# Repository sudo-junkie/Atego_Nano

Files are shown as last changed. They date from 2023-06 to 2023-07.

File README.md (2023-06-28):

# Atego Nano

KiCad 7 design files (schematic, PCB, gerber, BOM) for an Arduino Nano clone, with the following additional features:
-	Single cell lithium battery charger
-	VIN upto 15V
-	USB C
-	RGB LEDs

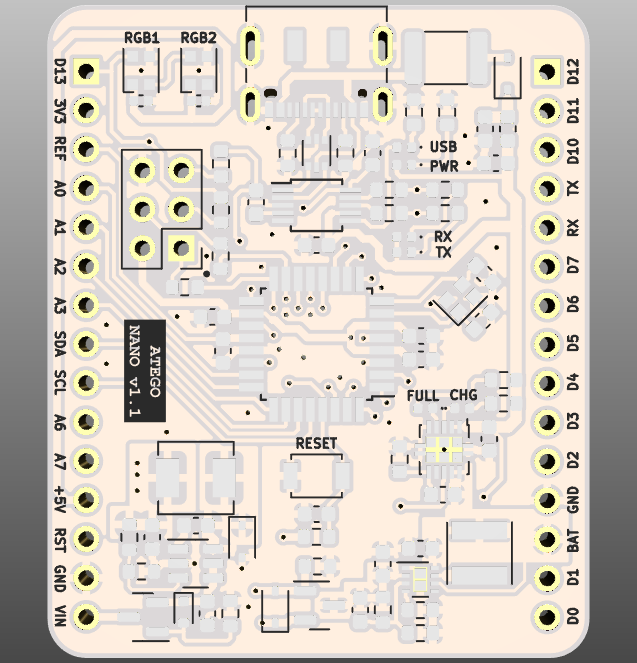
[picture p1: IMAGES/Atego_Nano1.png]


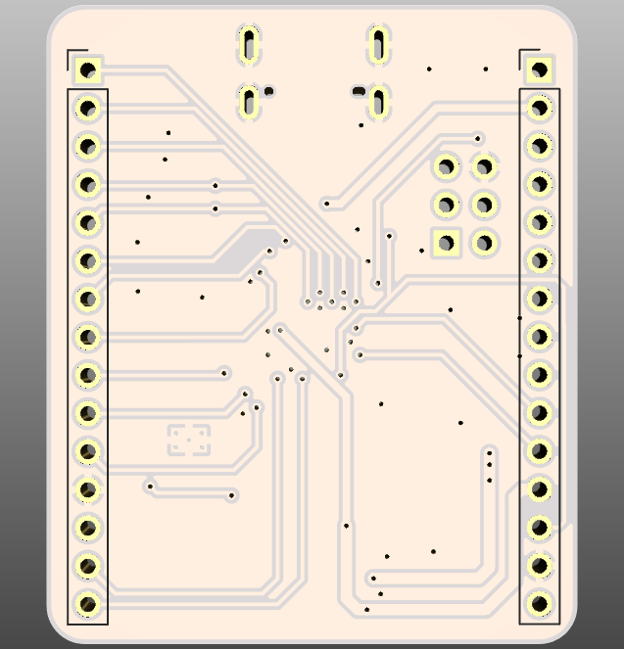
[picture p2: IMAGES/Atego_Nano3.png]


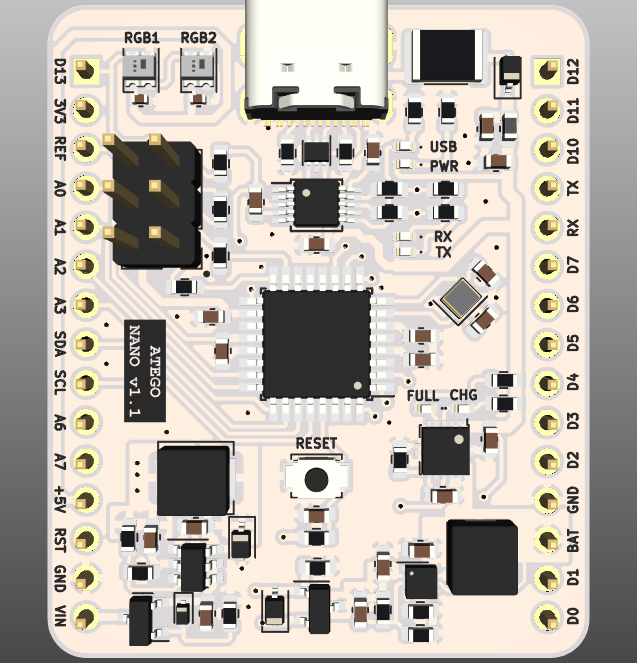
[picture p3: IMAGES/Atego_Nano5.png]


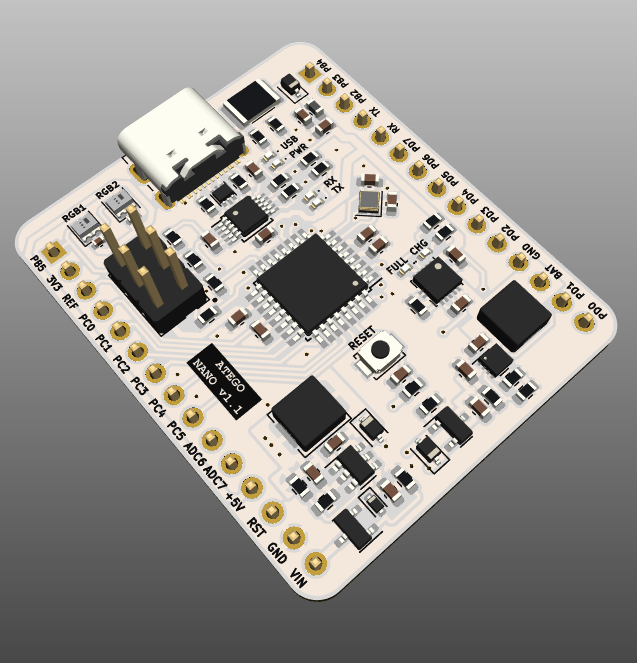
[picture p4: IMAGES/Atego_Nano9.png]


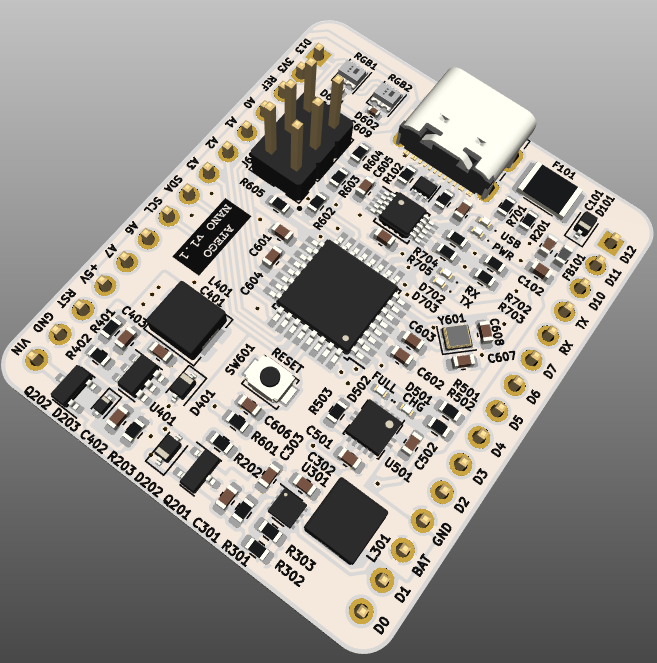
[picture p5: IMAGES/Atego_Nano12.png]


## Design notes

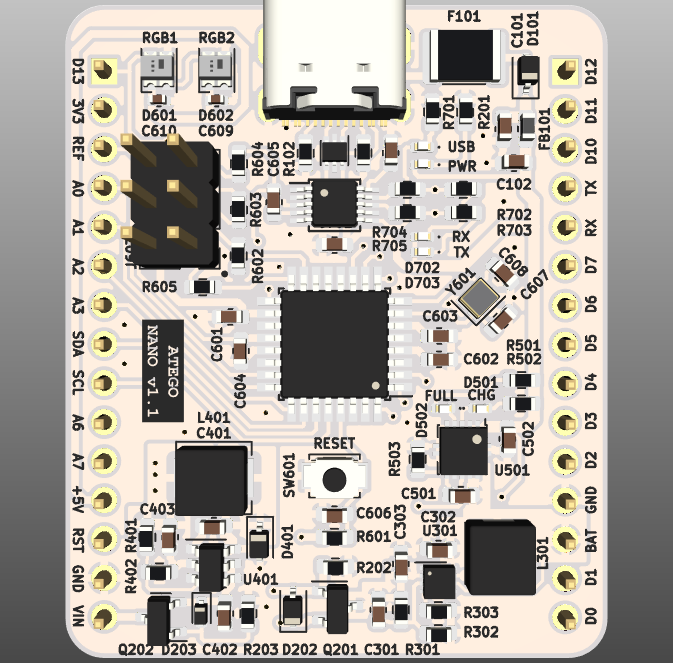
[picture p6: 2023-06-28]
IMAGES/Atego_Nano4.png

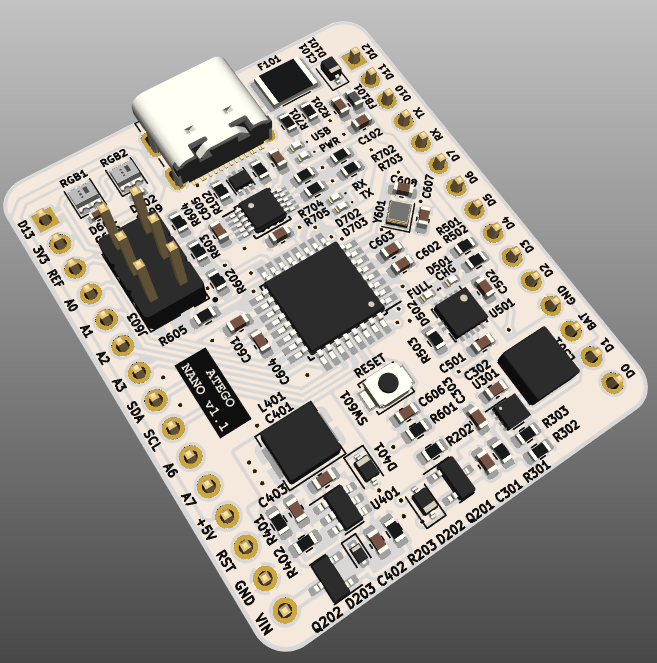
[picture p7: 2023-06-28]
IMAGES/Atego_Nano11.png

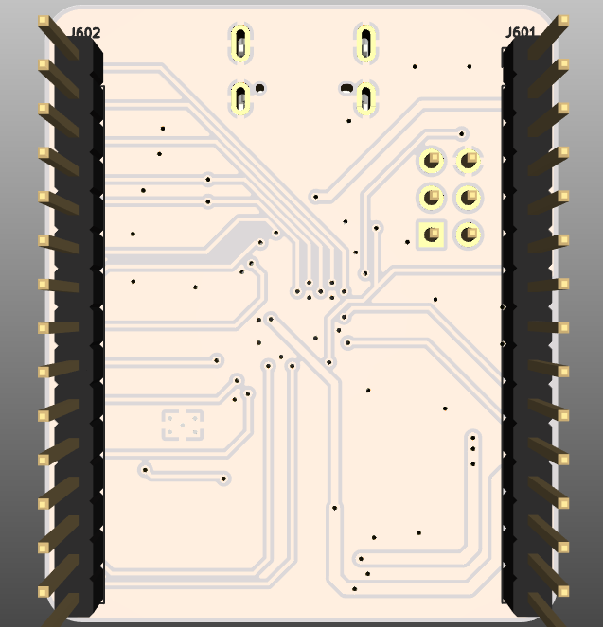
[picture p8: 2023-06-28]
IMAGES/Atego_Nano6.png

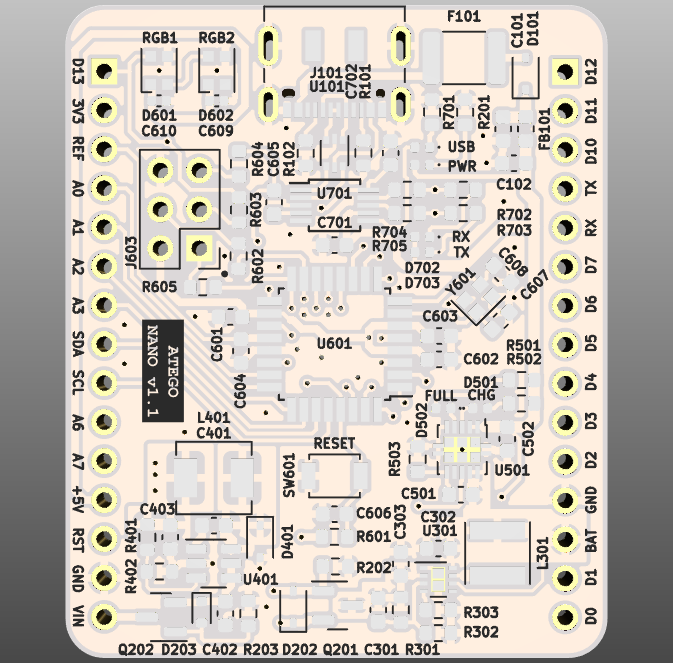
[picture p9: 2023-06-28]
IMAGES/Atego_Nano.png

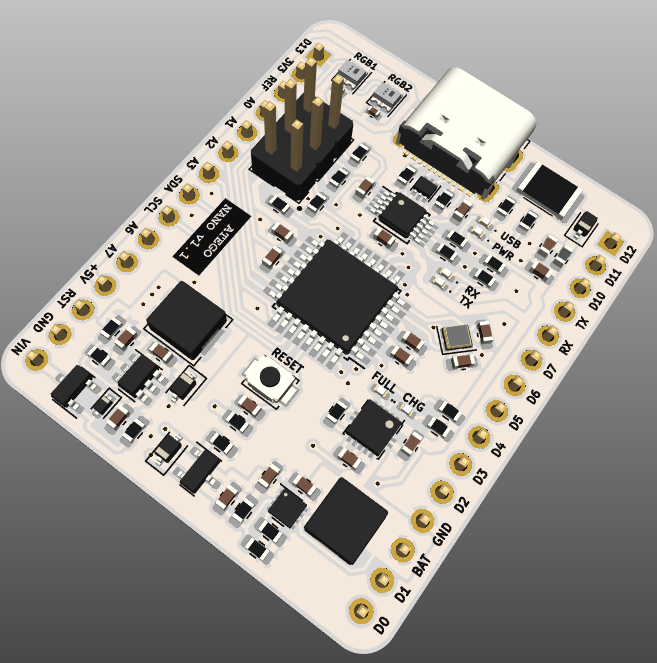
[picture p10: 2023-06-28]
IMAGES/Atego_Nano10.png

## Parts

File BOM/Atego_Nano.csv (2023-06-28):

Reference | Value | Footprint | MPN | MANUFACTURER | Price | Vendor | Qty
C101, C102, C602, C605, C606 | 1u 10% 10V | Capacitor_SMD:C_0603_1608Metric | CC0603KRX7R6BB105 | YAGEO | 0.0032 | LCSC | 5
C301 | 100p 1% 50V | Capacitor_SMD:C_0603_1608Metric | CC0603FRNPO9BN101 | YAGEO | 0.0086 | LCSC | 1
C302, C402 | 10u 20% 25V | Capacitor_SMD:C_0603_1608Metric | CC0603MRX5R8BB106 | YAGEO | 0.0427 | LCSC | 2
C303, C403 | 22u 20% 10V | Capacitor_SMD:C_0603_1608Metric | CC0603MRX5R6BB226 | YAGEO | 0.0352 | LCSC | 2
C401 | 10n 10% 10V | Capacitor_SMD:C_0603_1608Metric | CC0603KRX7R6BB103 | YAGEO | 0.004 | LCSC | 1
C501, C601, C603, C604, C701, C702 | 100n 10% 10V | Capacitor_SMD:C_0603_1608Metric | CC0603KRX7R6BB104 | YAGEO | 0.0032 | LCSC | 6
C502 | 470n 10% 16V | Capacitor_SMD:C_0603_1608Metric | CC0603KRX7R7BB474 | YAGEO | 0.0075 | LCSC | 1
C607, C608 | 22p 1% 50V | Capacitor_SMD:C_0603_1608Metric | CC0603FRNPO9BN220 | YAGEO | 0.0089 | LCSC | 2
C609, C610 | 100n 10V 5% | Capacitor_SMD:C_0402_1005Metric | CC0402JRX7R6BB104 | YAGEO | 0.0017 | LCSC | 2
D101, D202, D401 | ES3A-ES3J | Diode_SMD:D_SOD-323 | ES3AF | Shandong Jingdao Microelectronics | 0.0374 | LCSC | 3
D201 | LED_PWR | LED_SMD:LED_0402_1005Metric | XL-1005SURC | XINGLIGHT | 0.0067 | LCSC | 1
D203 | 11V | Diode_SMD:D_SOD-523 | BZX584C11V | Yangzhou Yangjie Elec Tech | 0.0147 | LCSC | 1
D501 | LED_R | LED_SMD:LED_0402_1005Metric | XL-1005SURC | XINGLIGHT | 0.0067 | LCSC | 1
D502 | LED_G | LED_SMD:LED_0402_1005Metric | XL-1005UGC | XINGLIGHT | 0.0067 | LCSC | 1
D601, D602 | WS2812B | LED_SMD:LED_WS2812B-2020_PLCC4_2.0x2.0mm | XL-2020RGBC-WS2812B | XINGLIGHT | 0.0738 | LCSC | 2
D701 | LED_USB_ACT | LED_SMD:LED_0402_1005Metric | XL-1005UBC | XINGLIGHT | 0.0066 | LCSC | 1
D702 | LED_TX | LED_SMD:LED_0402_1005Metric | XL-1005UOC | XINGLIGHT | 0.01 | LCSC | 1
D703 | LED_RX | LED_SMD:LED_0402_1005Metric | XL-1005UOC | XINGLIGHT | 0.01 | LCSC | 1
F101 | 500mA | Resistor_SMD:R_1812_4532Metric | MF-MSMF050-2 | BOURNS | 0.046 | LCSC | 1
FB101 | 220R@100MHz 1.5A | Inductor_SMD:L_0603_1608Metric | HPZ1608D221-1R5TF | Sunlord | 0.0146 | LCSC | 1
J101 | USB_C_Receptacle_USB2.0 | Connector_USB:USB_C_Receptacle_JAE_DX07S016JA1R1500 | TYPE-C 24P QT 143 | SHOU HAN | 0.3264 | LCSC | 1
J601 | Conn_L | Connector_PinHeader_2.54mm:PinHeader_1x15_P2.54mm_Vertical | B-2100S15P-A110 | Ckmtw(Shenzhen Cankemeng) | 0.0732 | LCSC | 1
J602 | Conn_R | Connector_PinHeader_2.54mm:PinHeader_1x15_P2.54mm_Vertical | B-2100S15P-A110 | Ckmtw(Shenzhen Cankemeng) | 0.0732 | LCSC | 1
J603 | Conn_ICSP | Connector_PinHeader_2.54mm:PinHeader_2x03_P2.54mm_Vertical | PH-01291 | Liansheng | 0.0207 | LCSC | 1
L301 | 1u | Inductor_SMD:L_Vishay_IFSC-1515AH_4x4x1.8mm | PSPNAQ4018-1R0M | PROD Tech | 0.0398 | LCSC | 1
L401 | 4u7 | Inductor_SMD:L_Sunlord_MWSA0402S | PSPMAA0402-4R7M-ANP | PROD Tech | 0.1549 | LCSC | 1
Q201, Q202 | AO3401A | Package_TO_SOT_SMD:SOT-23 | AO3401CI-MS | MSKSEMI | 0.0275 | LCSC | 2
R101, R102 | 5K1 5% | Resistor_SMD:R_0603_1608Metric | RC0603JR-075K1L | YAGEO | 0.0011 | LCSC | 2
R201, R501-R503, R602-R605, R701, R704, R705 | 1K 0.1% | Resistor_SMD:R_0603_1608Metric | RT0603BRD071KL | YAGEO | 0.0227 | LCSC | 11
R202, R203, R303, R601 | 10K 0.1% | Resistor_SMD:R_0603_1608Metric | RT0603BRD0710KL | YAGEO | 0.0222 | LCSC | 4
R301 | 768K | Resistor_SMD:R_0603_1608Metric | PTFR0603B768KP9 | Resistor.Today | 0.1092 | LCSC | 1
R302 | 243K | Resistor_SMD:R_0603_1608Metric | RT0603BRD07243KL | YAGEO | 0.028 | LCSC | 1
R401 | 180K 0.1% | Resistor_SMD:R_0603_1608Metric | RT0603BRD07180KL | YAGEO | 0.0238 | LCSC | 1
R402 | 33K | Resistor_SMD:R_0603_1608Metric | RT0603BRD0733KL | YAGEO | 0.0266 | LCSC | 1
R702, R703 | 470R 5% | Resistor_SMD:R_0603_1608Metric | RC0603JR-07470RL | YAGEO | 0.001 | LCSC | 2
SW601 | SW_RST | Button_Switch_SMD:SW_SPST_B3U-1000P | B3U-1000P | Omron Electronics | 0.2648 | LCSC | 1
U101 | USBLC6-2P6 | Package_TO_SOT_SMD:SOT-666 | USBLC6-2P6-ES | ElecSuper | 0.0816 | LCSC | 1
U301 | TPS61252DSG | Package_SON:WSON-8-1EP_2x2mm_P0.5mm_EP0.9x1.6mm | TPS61252DSGR | Texas Instruments | 1.7691 | LCSC | 1
U401 | AP3211K | Package_TO_SOT_SMD:SOT-23-6 | AP3211KTR-G1 | Diodes Incorporated | 0.1901 | LCSC | 1
U501 | BQ24012 | Package_SON:VSON-10-1EP_3x3mm_P0.5mm_EP1.65x2.4mm_ThermalVias | BQ24012DRCR | Texas Instruments | 1.8169 | LCSC | 1
U601 | ATmega328P-A | Package_QFP:TQFP-32_7x7mm_P0.8mm | ATMEGA328P-AU | Microchip Tech | 2.4246 | LCSC | 1
U701 | CH340E | Package_SO:MSOP-10_3x3mm_P0.5mm | CH340E | WCH(Jiangsu Qin Heng) | 0.5807 | LCSC | 1
Y601 | 16MHz | Crystal:Crystal_SMD_2016-4Pin_2.0x1.6mm | TJ2116000UYGBC | JYJE | 0.1504 | LCSC | 1

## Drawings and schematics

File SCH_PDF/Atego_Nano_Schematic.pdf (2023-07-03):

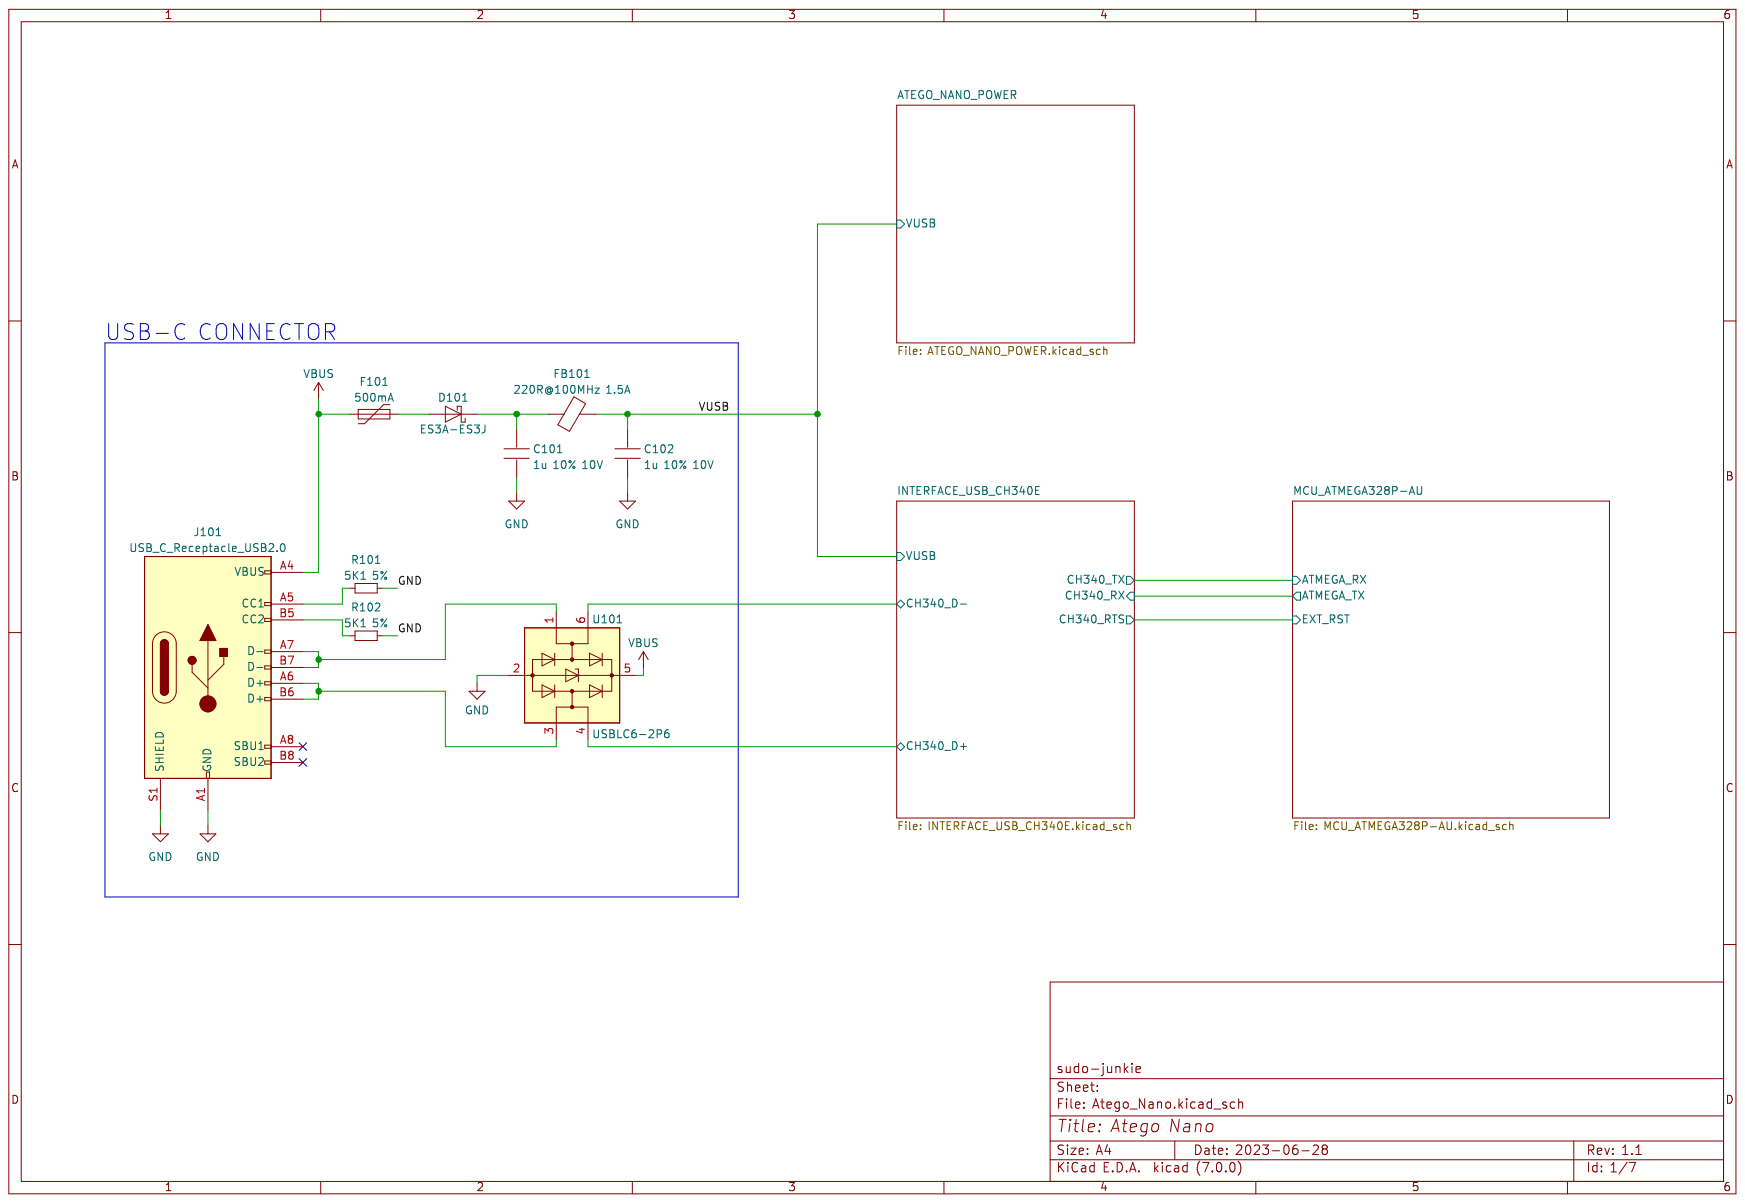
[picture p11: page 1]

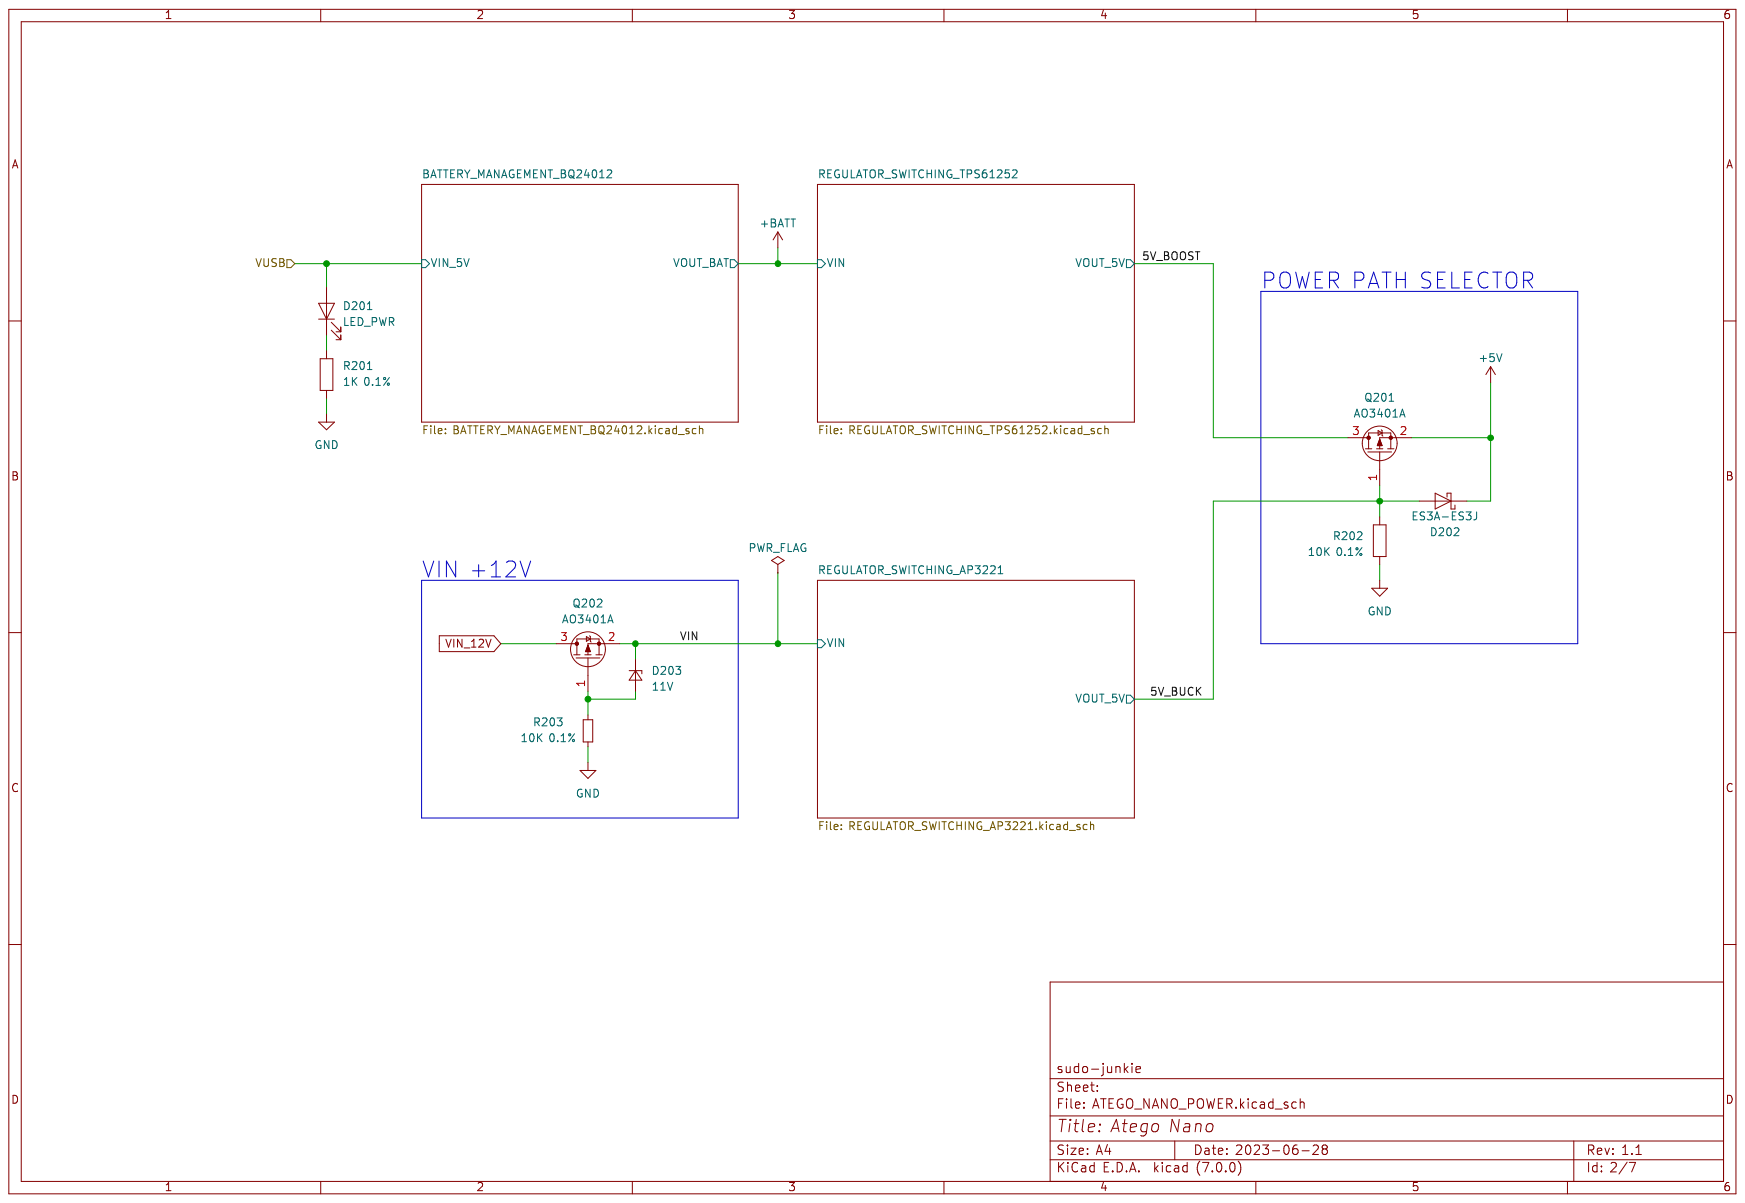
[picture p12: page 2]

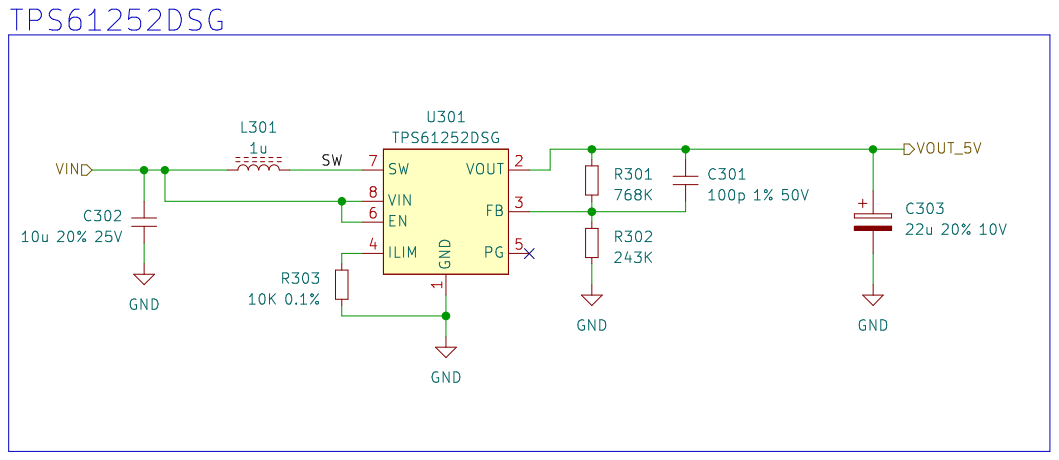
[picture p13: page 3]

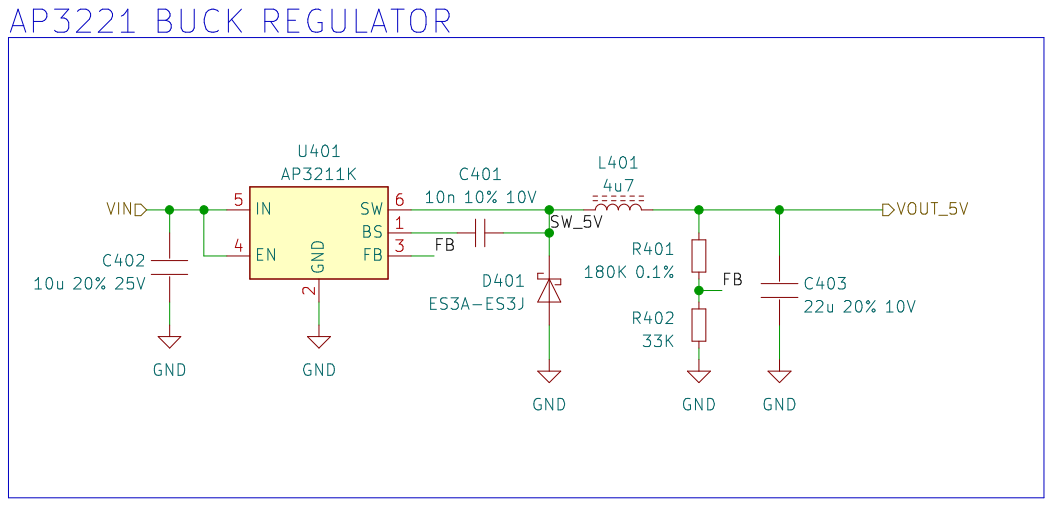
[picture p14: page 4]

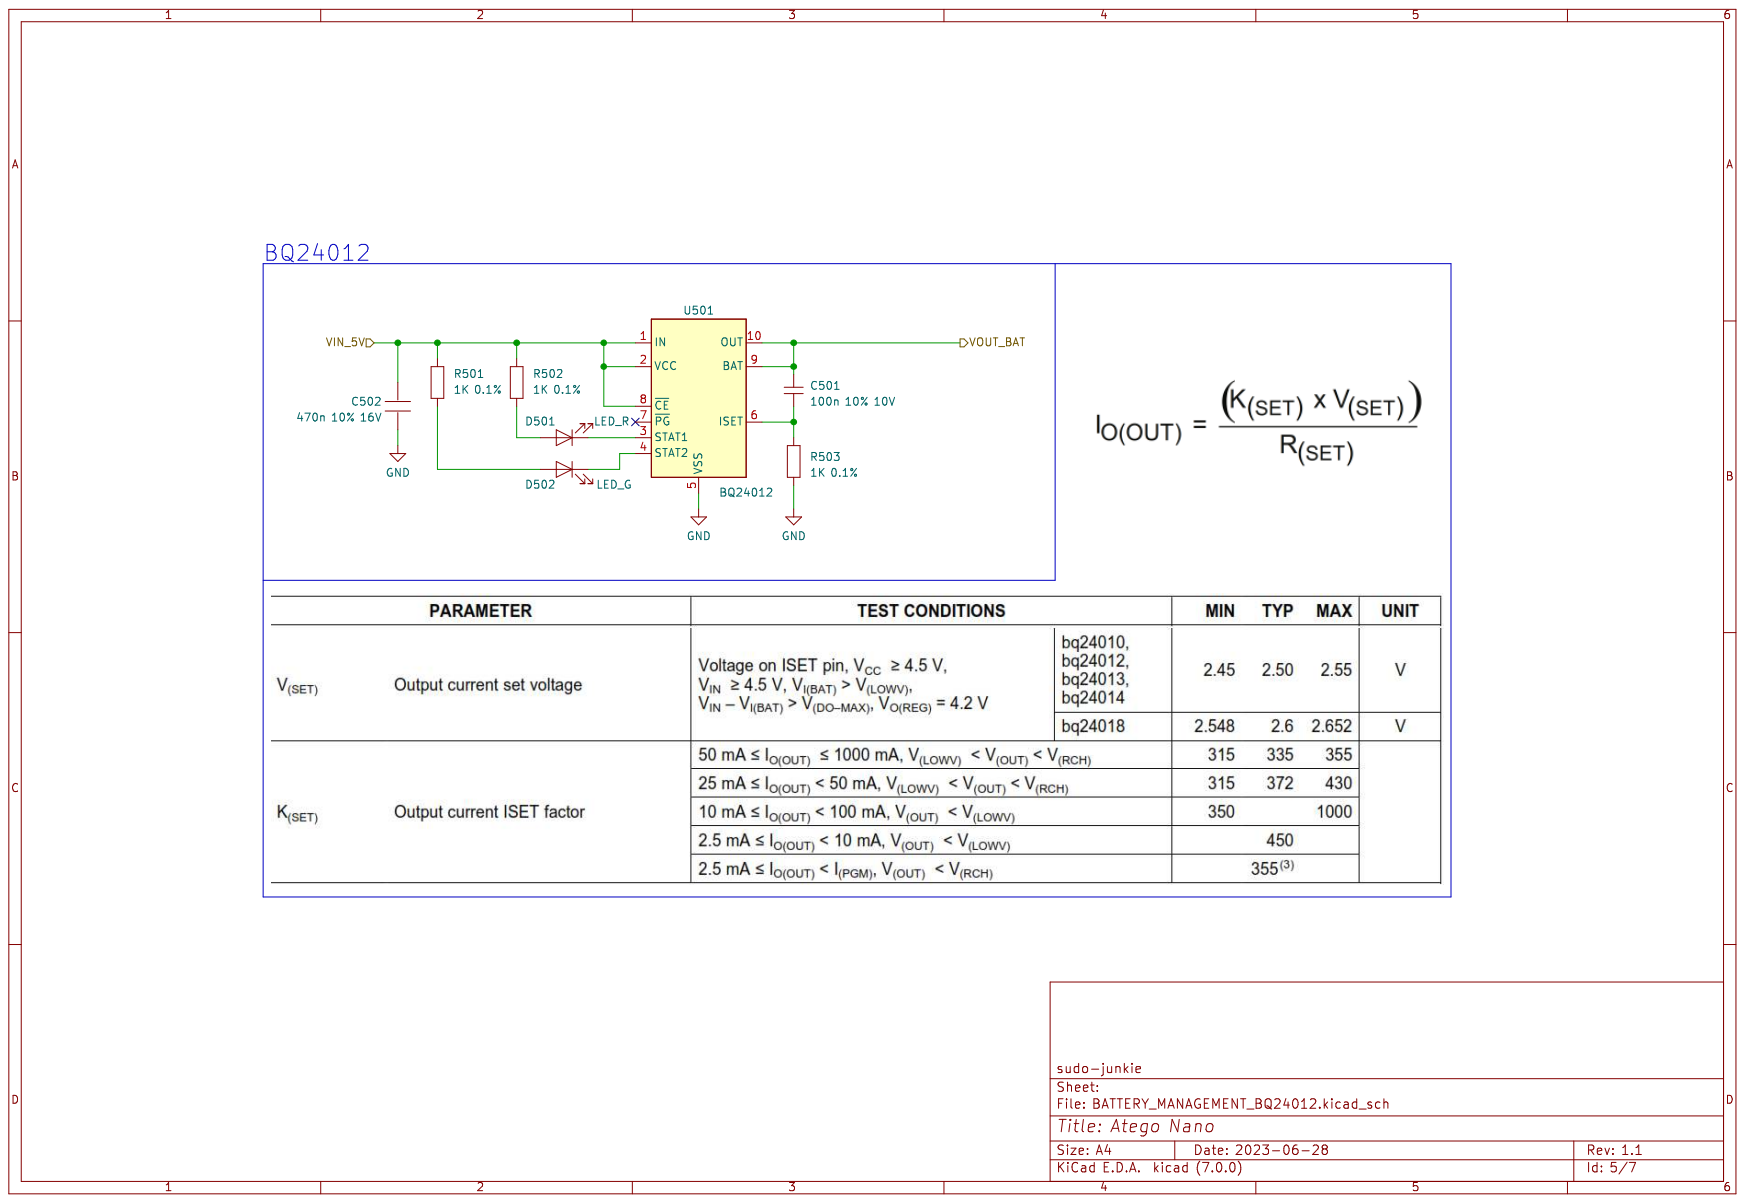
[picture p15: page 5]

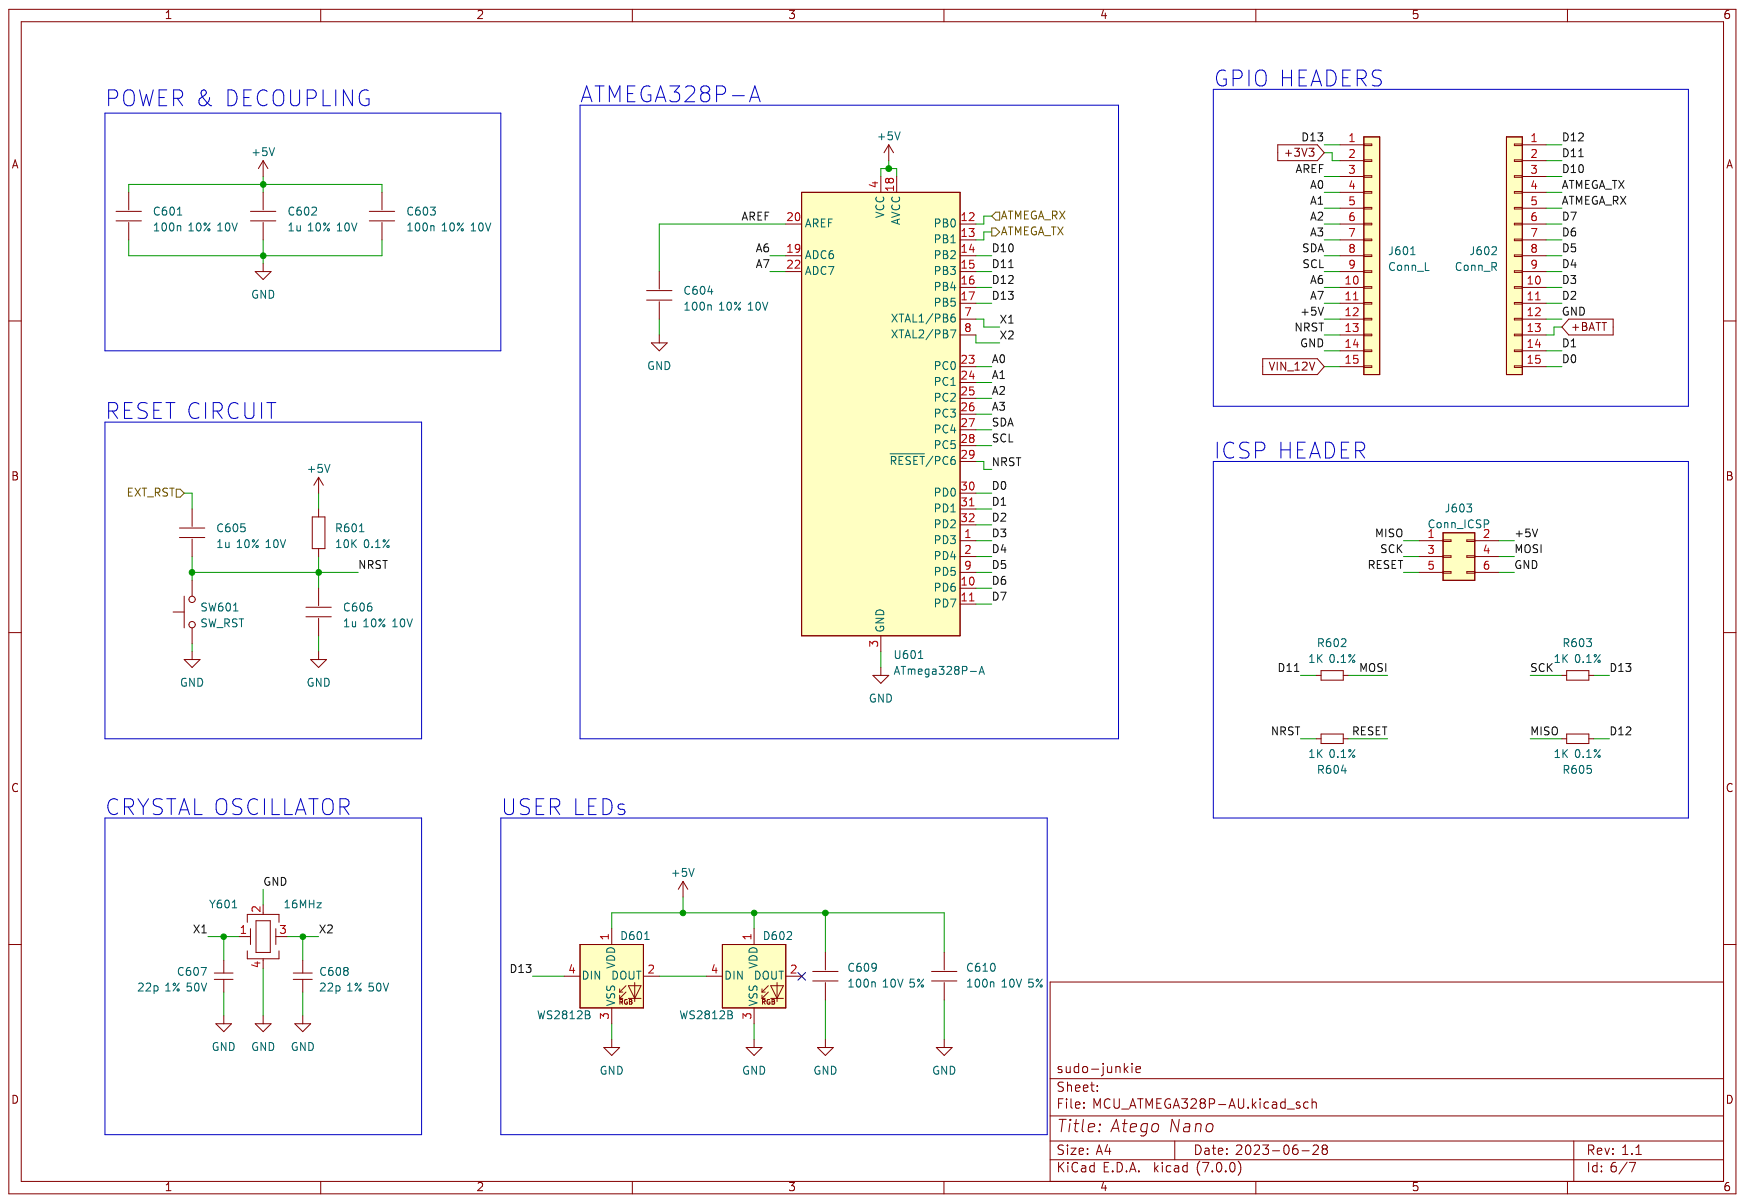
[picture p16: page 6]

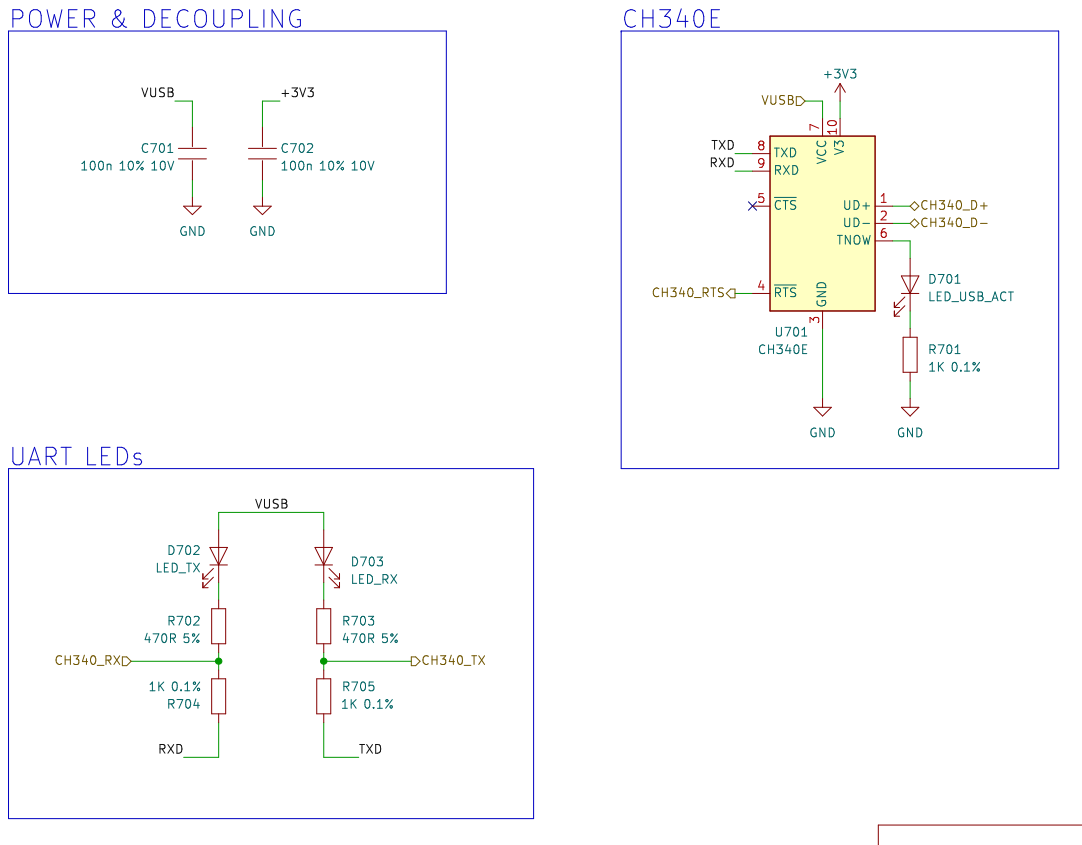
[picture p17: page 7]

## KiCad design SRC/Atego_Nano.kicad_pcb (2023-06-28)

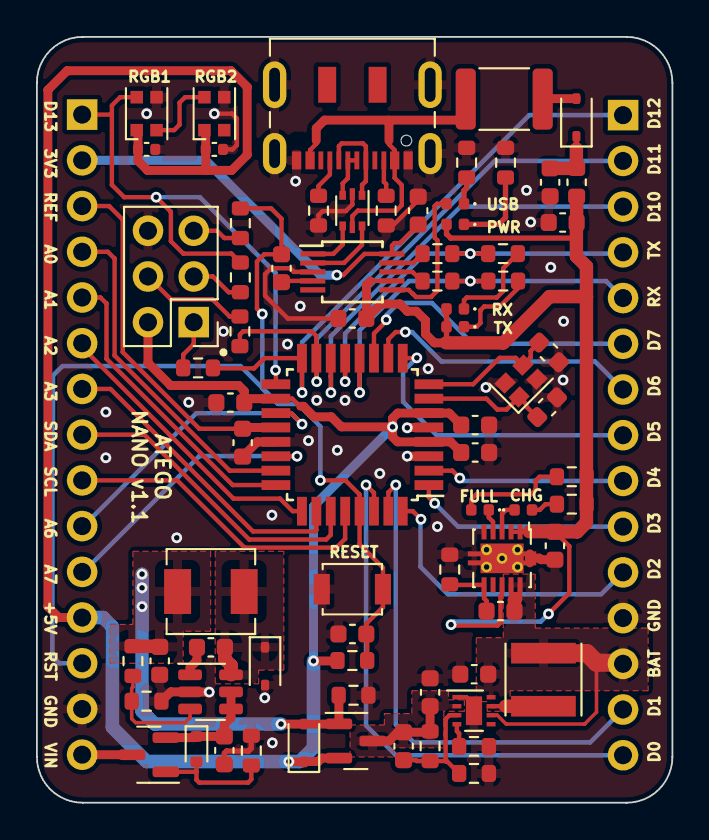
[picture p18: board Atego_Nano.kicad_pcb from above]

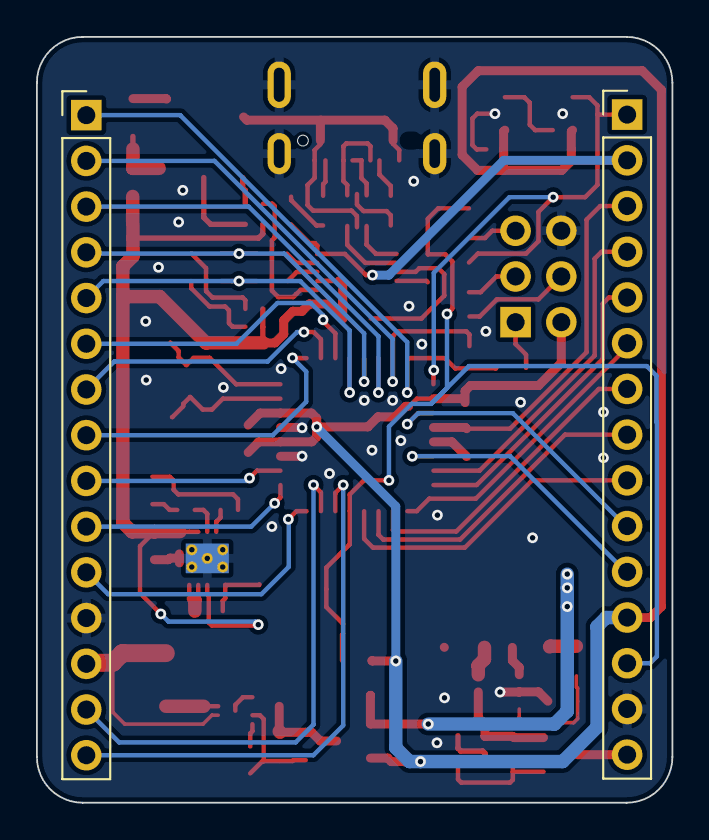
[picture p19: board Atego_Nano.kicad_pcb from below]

Board: 2 copper layers, 35.3 x 42.5 mm, 75 parts (2 on the bottom side), 69 nets.

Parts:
C101, C102, C602, C605, C606: 1u 10% 10V; C_0603_1608Metric
C301: 100p 1% 50V; C_0603_1608Metric
C302, C402: 10u 20% 25V; C_0603_1608Metric
C303, C403: 22u 20% 10V; C_0603_1608Metric
C401: 10n 10% 10V; C_0603_1608Metric
C501, C601, C603, C604, C701, C702: 100n 10% 10V; C_0603_1608Metric
C502: 470n 10% 16V; C_0603_1608Metric
C607, C608: 22p 1% 50V; C_0603_1608Metric
C609, C610: 100n 10V 5%; C_0402_1005Metric
D101, D202, D401: ES3A-ES3J; D_SOD-323
D201: LED_PWR; LED_0402_1005Metric
D203: 11V; D_SOD-523
D501: LED_R; LED_0402_1005Metric
D502: LED_G; LED_0402_1005Metric
D601, D602: WS2812B; LED_WS2812B-2020_PLCC4_2.0x2.0mm
D701: LED_USB_ACT; LED_0402_1005Metric
D702: LED_TX; LED_0402_1005Metric
D703: LED_RX; LED_0402_1005Metric
F101: 500mA; R_1812_4532Metric
FB101: 220R@100MHz 1.5A; L_0603_1608Metric
J101: USB_C_Receptacle_USB2.0; USB_C_Receptacle_JAE_DX07S016JA1R1500
J601: Conn_L; PinHeader_1x15_P2.54mm_Vertical
J602: Conn_R; PinHeader_1x15_P2.54mm_Vertical
J603: Conn_ICSP; PinHeader_2x03_P2.54mm_Vertical
L301: 1u; L_Vishay_IFSC-1515AH_4x4x1.8mm
L401: 4u7; L_Sunlord_MWSA0402S
Q201, Q202: AO3401A; SOT-23
R101, R102: 5K1 5%; R_0603_1608Metric
R201, R501, R502, R503, R602, R603, R604, R605, R701, R704, R705: 1K 0.1%; R_0603_1608Metric
R202, R203, R303, R601: 10K 0.1%; R_0603_1608Metric
R301: 768K; R_0603_1608Metric
R302: 243K; R_0603_1608Metric
R401: 180K 0.1%; R_0603_1608Metric
R402: 33K; R_0603_1608Metric
R702, R703: 470R 5%; R_0603_1608Metric
SW601: SW_RST; SW_SPST_B3U-1000P
U101: USBLC6-2P6; SOT-666
U301: TPS61252DSG; WSON-8-1EP_2x2mm_P0.5mm_EP0.9x1.6mm
U401: AP3211K; SOT-23-6
U501: BQ24012; VSON-10-1EP_3x3mm_P0.5mm_EP1.65x2.4mm_ThermalVias
U601: ATmega328P-A; TQFP-32_7x7mm_P0.8mm
U701: CH340E; MSOP-10_3x3mm_P0.5mm
Y601: 16MHz; Crystal_SMD_2016-4Pin_2.0x1.6mm

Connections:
+3V3: C702.1, J601.2, U701.10 (V3)
+5V: C601.1, C602.1, C603.1, C609.1, C610.1, D202.1 (K), D601.1 (VDD), D602.1 (VDD), J601.12, J603.2, Q201.2 (S), R601.1, U601.4 (VCC), U601.6 (VCC), U601.18 (AVCC)
+BATT: C302.1, C501.1, J602.13, L301.1, U301.6 (EN), U301.8 (VIN), U501.9 (BAT), U501.10 (OUT)
/ATEGO_NANO_POWER/5V_BOOST: C301.1, C303.1, Q201.3 (D), R301.1, U301.2 (VOUT)
/ATEGO_NANO_POWER/5V_BUCK: C403.1, D202.2 (A), L401.2, Q201.1 (G), R202.1, R401.1
/ATEGO_NANO_POWER/REGULATOR_SWITCHING_AP3221/FB: R401.2, R402.1, U401.3 (FB)
/ATEGO_NANO_POWER/REGULATOR_SWITCHING_AP3221/SW_5V: C401.2, D401.1 (K), L401.1, U401.6 (SW)
/ATEGO_NANO_POWER/REGULATOR_SWITCHING_TPS61252/SW: L301.2, U301.7 (SW)
/ATEGO_NANO_POWER/VIN: C402.1, D203.1 (K), Q202.2 (S), U401.4 (EN), U401.5 (IN)
/INTERFACE_USB_CH340E/CH340_D+: U101.4 (I/O2), U701.1 (UD+)
/INTERFACE_USB_CH340E/CH340_D-: U101.6 (I/O1), U701.2 (UD-)
/INTERFACE_USB_CH340E/CH340_RTS: C605.1, U701.4 (~RTS)
/INTERFACE_USB_CH340E/RXD: R704.2, U701.9 (RXD)
/INTERFACE_USB_CH340E/TXD: R705.2, U701.8 (TXD)
/MCU_ATMEGA328P-AU/A0: J601.4, U601.23 (PC0)
/MCU_ATMEGA328P-AU/A1: J601.5, U601.24 (PC1)
/MCU_ATMEGA328P-AU/A2: J601.6, U601.25 (PC2)
/MCU_ATMEGA328P-AU/A3: J601.7, U601.26 (PC3)
/MCU_ATMEGA328P-AU/A6: J601.10, U601.19 (ADC6)
/MCU_ATMEGA328P-AU/A7: J601.11, U601.22 (ADC7)
/MCU_ATMEGA328P-AU/AREF: C604.1, J601.3, U601.20 (AREF)
/MCU_ATMEGA328P-AU/ATMEGA_RX: J602.5, R703.2, R705.1, U601.12 (PB0)
/MCU_ATMEGA328P-AU/ATMEGA_TX: J602.4, R702.2, R704.1, U601.13 (PB1)
/MCU_ATMEGA328P-AU/D0: J602.15, U601.30 (PD0)
/MCU_ATMEGA328P-AU/D1: J602.14, U601.31 (PD1)
/MCU_ATMEGA328P-AU/D2: J602.11, U601.32 (PD2)
/MCU_ATMEGA328P-AU/D3: J602.10, U601.1 (PD3)
/MCU_ATMEGA328P-AU/D4: J602.9, U601.2 (PD4)
/MCU_ATMEGA328P-AU/D5: J602.8, U601.9 (PD5)
/MCU_ATMEGA328P-AU/D6: J602.7, U601.10 (PD6)
/MCU_ATMEGA328P-AU/D7: J602.6, U601.11 (PD7)
/MCU_ATMEGA328P-AU/D10: J602.3, U601.14 (PB2)
/MCU_ATMEGA328P-AU/D11: J602.2, R602.1, U601.15 (PB3)
/MCU_ATMEGA328P-AU/D12: J602.1, R605.2, U601.16 (PB4)
/MCU_ATMEGA328P-AU/D13: D601.4 (DIN), J601.1, R603.2, U601.17 (PB5)
/MCU_ATMEGA328P-AU/MISO: J603.1, R605.1
/MCU_ATMEGA328P-AU/MOSI: J603.4, R602.2
/MCU_ATMEGA328P-AU/NRST: C605.2, C606.1, J601.13, R601.2, R604.1, SW601.2, U601.29 (~RESET/PC6)
/MCU_ATMEGA328P-AU/RESET: J603.5, R604.2
/MCU_ATMEGA328P-AU/SCK: J603.3, R603.1
/MCU_ATMEGA328P-AU/SCL: J601.9, U601.28 (PC5)
/MCU_ATMEGA328P-AU/SDA: J601.8, U601.27 (PC4)
/MCU_ATMEGA328P-AU/X1: C607.1, U601.7 (XTAL1/PB6), Y601.1
/MCU_ATMEGA328P-AU/X2: C608.1, U601.8 (XTAL2/PB7), Y601.3
/VUSB: C102.1, C502.1, C701.1, D201.2 (A), D702.2 (A), D703.2 (A), FB101.2, R501.1, R502.1, U501.1 (IN), U501.2 (VCC), U501.8 (~CE), U701.7 (VCC)
GND: C101.2, C102.2, C302.2, C303.2, C402.2, C403.2, C502.2, C601.2, C602.2, C603.2, C604.2, C606.2, C607.2, C608.2, C609.2, C610.2, C701.2, C702.2, D401.2 (A), D601.3 (VSS), D602.3 (VSS), J101.A1 (GND), J101.A12 (GND), J101.B1 (GND), J101.B12 (GND), J101.S1 (SHIELD), J601.14, J602.12, J603.6, R101.2, R102.2, R201.2, R202.2, R203.2, R302.2, R303.2, R402.2, R503.2, R701.2, SW601.1, U101.2 (GND), U301.1 (GND), U301.9 (GND), U401.2 (GND), U501.5 (VSS), U501.11 (VSS), U601.3 (GND), U601.5 (GND), U601.21 (GND), U701.3 (GND), Y601.2, Y601.4
unnamed: D101.2 (A), F101.2
unnamed: C101.1, D101.1 (K), FB101.1
unnamed: D201.1 (K), R201.1
unnamed: D203.2 (A), Q202.1 (G), R203.1
unnamed: D501.2 (A), R502.2
unnamed: D501.1 (K), U501.3 (STAT1)
unnamed: D502.2 (A), R501.2
unnamed: D502.1 (K), U501.4 (STAT2)
unnamed: D601.2 (DOUT), D602.4 (DIN)
unnamed: D701.2 (A), U701.6 (TNOW)
unnamed: D701.1 (K), R701.1
unnamed: D702.1 (K), R702.1
unnamed: D703.1 (K), R703.1
unnamed: J101.A5 (CC1), R101.1
unnamed: J101.B5 (CC2), R102.1
unnamed: J101.A6 (D+), J101.B6 (D+), U101.3 (I/O2)
unnamed: J101.A7 (D-), J101.B7 (D-), U101.1 (I/O1)
unnamed: C301.2, R301.2, R302.1, U301.3 (FB)
unnamed: R303.1, U301.4 (ILIM)
unnamed: C401.1, U401.1 (BS)
unnamed: C501.2, R503.1, U501.6 (ISET)
VBUS: F101.1, J101.A4 (VBUS), J101.A9 (VBUS), J101.B4 (VBUS), J101.B9 (VBUS), U101.5 (VBUS)
VIN_12V: J601.15, Q202.3 (D)
